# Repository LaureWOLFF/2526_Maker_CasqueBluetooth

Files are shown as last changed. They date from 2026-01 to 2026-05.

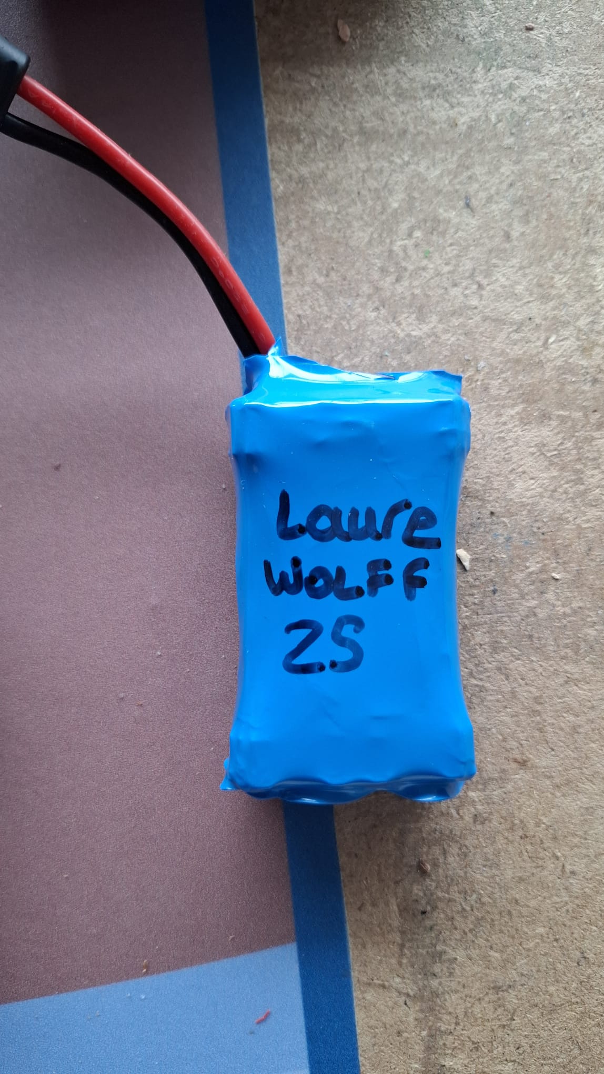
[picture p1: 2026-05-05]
TDs/Batterie/WhatsApp Image 2026-05-05 at 19.35.17.jpeg

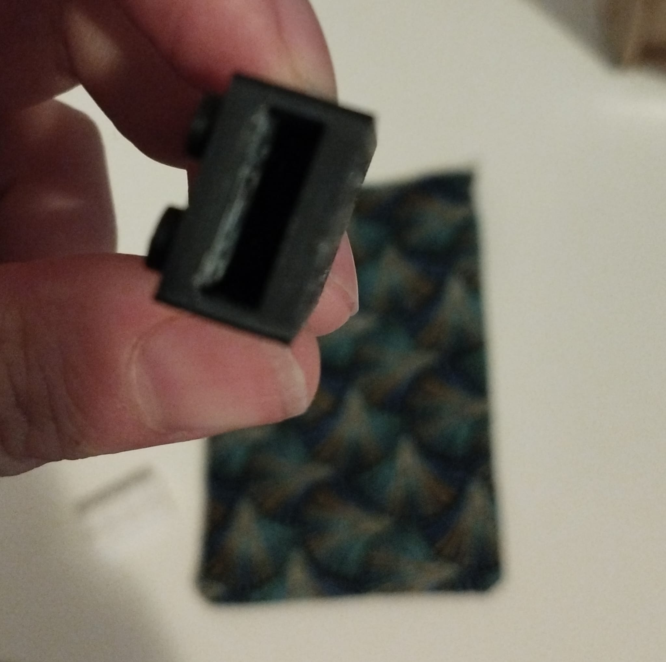
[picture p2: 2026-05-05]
TDs/impressions 3D et couture/WhatsApp Image 2026-05-05 at 10.13.26.jpeg

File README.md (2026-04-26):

# 🎧 2526_Maker_CasqueBluetooth: Création d'un casque bluetooth DIY

## 📌 Présentation du Projet

Le but de ce projet est de créer un casque bluetooth en mobilisant les compétences apprises lors de l'option **Maker** de deuxième année de l'**ENSEA**. Pour réaliser ce casque, le choix du microcontroleur c'est porté sur l'utilisation d'un **ESP32-S3-MINI-1-N8**. La structure mécanique a été entièrement modélisée sur **Onshape** avec une attention particulière portée à l'intégration électronique et à la durabilité tandis que la conception électronique a été réalisée sur Kicad.

### Caractéristiques Principales
* **Micronctroleur :** ESP32-S3-MINI-N8.
* **Diamètre des oreillettes :** 82 mm.
* **Interface :** Contrôle du volume et lecture via 3 boutons physiques (GPIO 0, 1, 2).
* **Connectivité :** USB-C 16 pins.
* **Architecture Audio :** Flux numérique I2S (Pins 6, 7, 8) vers DAC/Ampli.

---

## 🛠 Technologies & Outils
* **Mécanique :** Onshape (Modélisation 3D).
* **Électronique :** KiCad (Conception du PCB).
* **Développement :** Arduino IDE 1.8.19.

## 📋 État du Prototype
* **Hardware :** PCB soudé et fonctionnel (LED verte OK).
* **Mécanique :** Impression 3D terminée et finalisée.
* **Firmware :** En cours d'optimisation pour la reconnaissance USB Audio.

---

## ⚡L'impasse du Bluetooth classique sur l'ESP32-S3

Lors de la progammation du PCB, un problème est intervenu. Il est impossible de compiler le code car l'ESP32-S2-MINI-N8. En effet conttairement au téléphone qui a un protocole bluetooth pour l'audio de A2DP (Classic), l'ESP32 ne finctionne que en Bluetooth LE. Cette erreur dans le choix du composant a empecher de réliser  la finialisation de ce pojet. Car la bibliothèque de référence `ESP32-A2DP` est= incompatible avec cette puce. Le S3 est conçu pour le **Bluetooth LE (Low Energy)** et le futur standard **LE Audio**, qui nécessite un smartphone très récent.

    1. Modification du PCB
Pour palierà ce problème, une possibilité eest d'ajoutéé un module Bluetooth Audio dédié gérant le profil A2DP. Ainsi ainsi l'ESP32 serait utilisé pour traiter l'information (la munique) et le module pour la transmmetre. Cependant, le PCB devait être modifier et avec le délai serré, il était impossible de commander un nouveau PCB modifié.

    2. La solution Wi-Fi
Il existe une possibilitée d'utiliser le Wi-Fi pour le streaming (Spotify Connect). Cependant, le casque devenait dépendant d'un réseau Wi-Fi local, perdant son utilité en déplacement.

      3. La Solution USB DAC
Pour sauver le projet sans changer le PCB déjà soudé, une autre solution est envisageable vers un mode **USB DAC**. 
En utilisant les pins natives **D- (GPIO 19)** et **D+ (GPIO 20)** de l'ESP32-S3, le casque est reconnu comme une carte son externe par le téléphone. Ainsi, il y a la possibilité de transformer le prototype d'un casque bluetooth à un casque filiaire.

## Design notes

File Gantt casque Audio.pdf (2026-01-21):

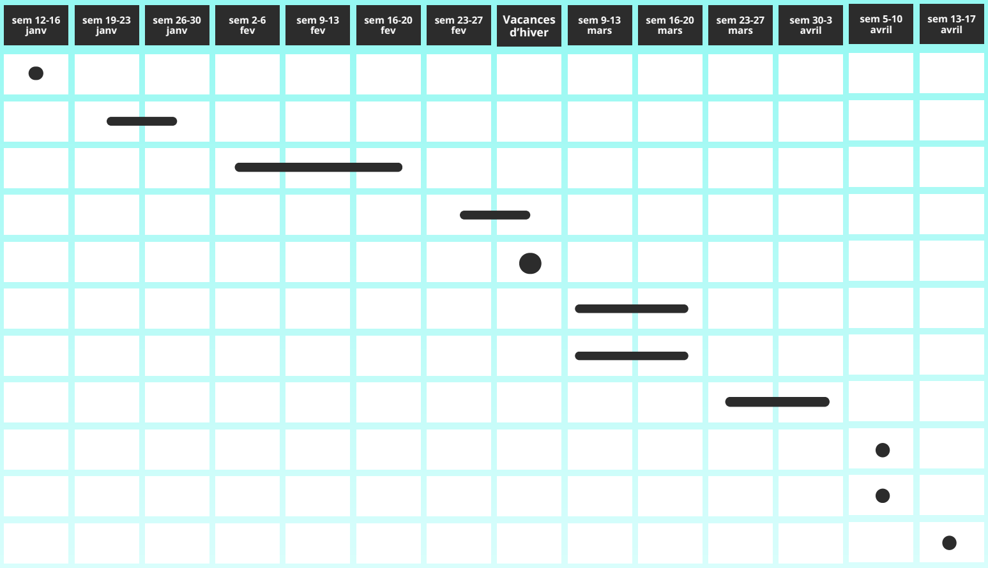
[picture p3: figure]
sem 12-16 janv; sem 19-23 janv; sem 26-30 janv; sem 2-6 fev; sem 9-13 fev; sem 16-20 fev; sem 23-27 fev; Vacances d’hiver; sem 9-13 mars; sem 16-20 mars; sem 23-27 mars; sem 30-3 avril; sem 5-10 avril; sem 13-17 avril

Recherche et commande
des composants

Définition du projet

Developpement du PCB

Commande et livraison du
PCB
Modélisation

Impression des éléments
mécanique

Soudure PCB

Programmation

Assemblage de l’ensemble

Test et validation

# Gantt diagram

Rendu / soutenance

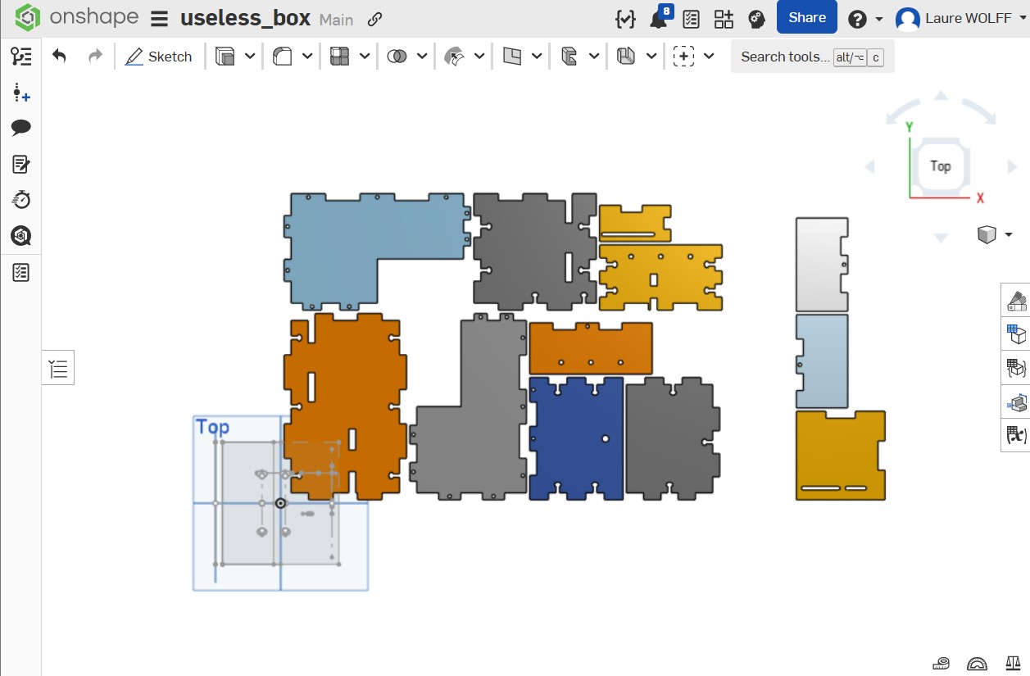
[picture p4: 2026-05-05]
TDs/découpeuse laser/CAO de la boite.jpg

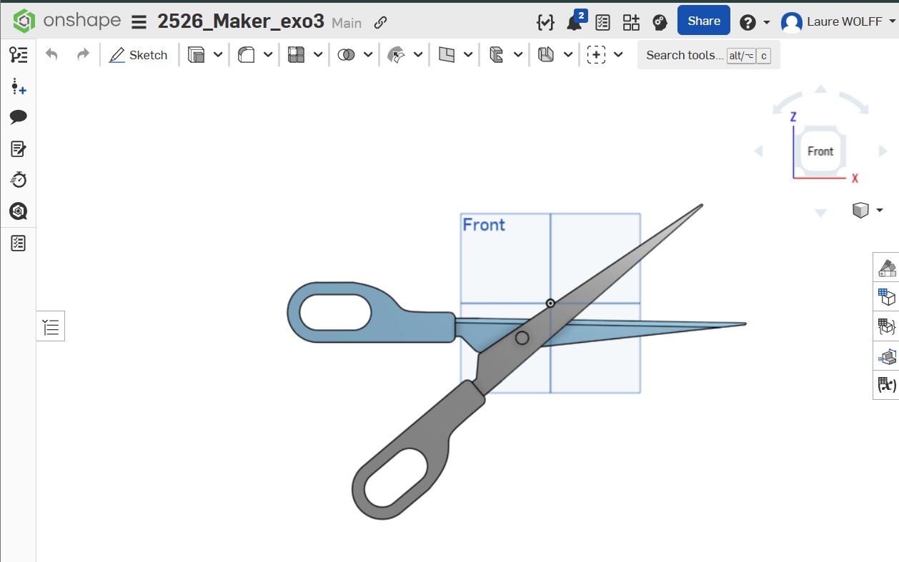
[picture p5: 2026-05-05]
TDs/CAO/CAO ciseaux.jpg

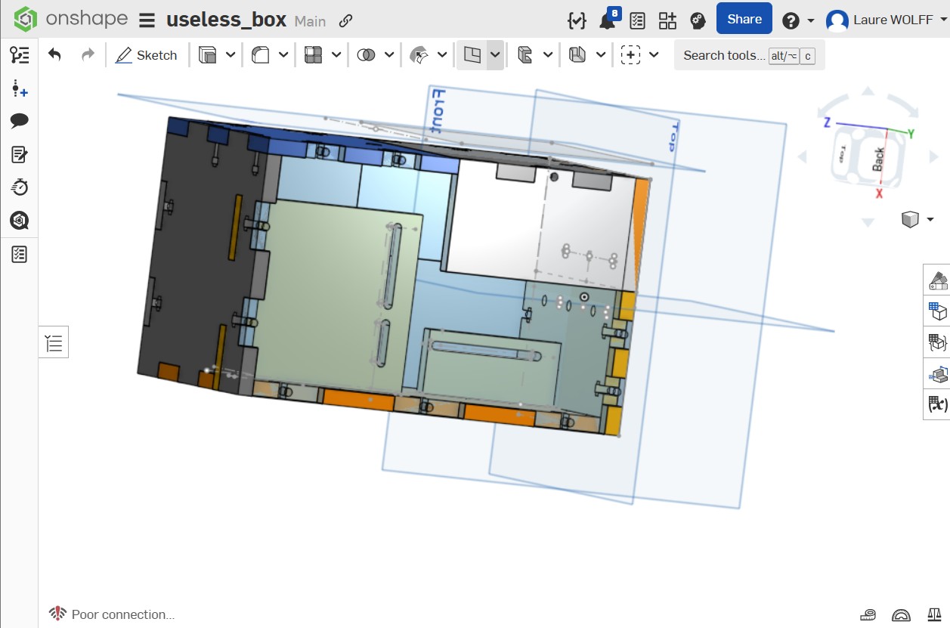
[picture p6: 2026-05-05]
TDs/découpeuse laser/visualisation 3D de la boite.jpg

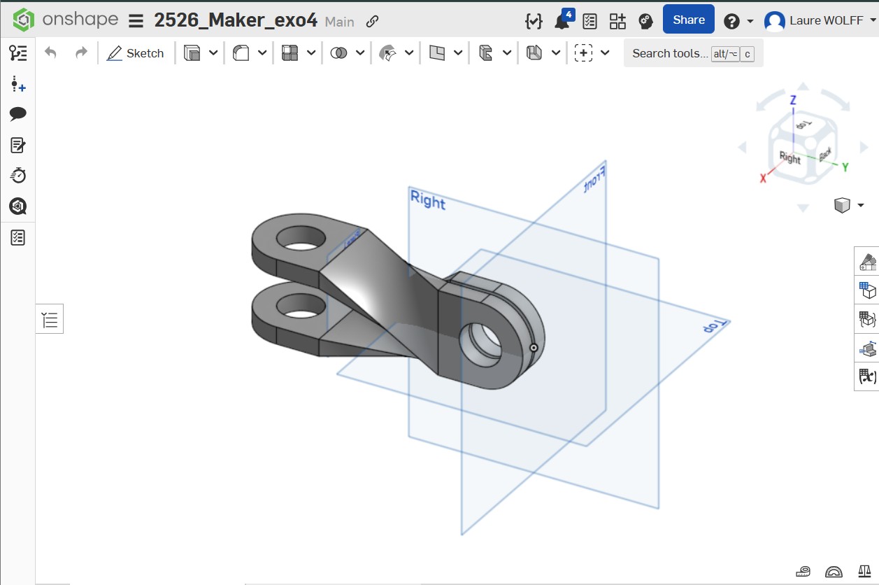
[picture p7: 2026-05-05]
TDs/CAO/CAO ecrou.jpg

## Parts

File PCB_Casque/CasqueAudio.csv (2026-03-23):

Reference | Value | Footprint | Datasheet | Qty | DNP | Exclude from BOM | Exclude from Board
C1,C2 | 1µ | Capacitor_SMD:C_0402_1005Metric_Pad0.74x0.62mm_HandSolder | ~ | 2
C3,C4 | 4.7µ | Capacitor_SMD:C_0402_1005Metric_Pad0.74x0.62mm_HandSolder | ~ | 2
C5 | 22µ | Capacitor_SMD:C_0603_1608Metric_Pad1.08x0.95mm_HandSolder | ~ | 1
C6,C9,C10 | 0.1µ | Capacitor_SMD:C_0402_1005Metric_Pad0.74x0.62mm_HandSolder | ~ | 3
C11,C12 | 10µ | Capacitor_SMD:C_0603_1608Metric_Pad1.08x0.95mm_HandSolder | ~ | 2
C14,C15,C16,C17 | 100n | Capacitor_SMD:C_0402_1005Metric_Pad0.74x0.62mm_HandSolder | ~ | 4
D1 | LED | LED_SMD:LED_0603_1608Metric_Pad1.05x0.95mm_HandSolder | ~ | 1
H1,H2,H3,H4 | MountingHole | MountingHole:MountingHole_2.7mm_M2.5 | ~ | 4 |  | Excluded from BOM
J1 | USB_C_Receptacle_USB2.0_16P | Connector_USB:USB_C_Receptacle_GCT_USB4105-xx-A_16P_TopMnt_Horizontal | https://www.usb.org/sites/default/files/documents/usb_type-c.zip | 1
J2 | Conn_01x02_Pin | Connector_JST:JST_PH_B2B-PH-K_1x02_P2.00mm_Vertical | ~ | 1
J3,J4,J5,J6 | Conn_01x01_Pin | TestPoint:TestPoint_Pad_D2.0mm | ~ | 4
R1,R2 | 5.1k | Resistor_SMD:R_0402_1005Metric_Pad0.72x0.64mm_HandSolder | ~ | 2
R3 | 470 | Resistor_SMD:R_0402_1005Metric_Pad0.72x0.64mm_HandSolder | ~ | 1
R4 | 4.7k | Resistor_SMD:R_0402_1005Metric_Pad0.72x0.64mm_HandSolder | ~ | 1
R5 | 200k | Resistor_SMD:R_0402_1005Metric_Pad0.72x0.64mm_HandSolder | ~ | 1
R7,R8,R9,R10,R11 | 10k | Resistor_SMD:R_0402_1005Metric_Pad0.72x0.64mm_HandSolder | ~ | 5
SW1,SW2,SW4 | SW_Push | Button_Switch_THT:SW_Tactile_SPST_Angled_PTS645Vx58-2LFS | ~ | 3
SW3,SW5 | SW_Push | 435171014816:435171014816 | ~ | 2
U1 | MCP73831-2-OT | Package_TO_SOT_SMD:SOT-23-5 | http://ww1.microchip.com/downloads/en/DeviceDoc/20001984g.pdf | 1
U2 | AP2112K-3.3 | Package_TO_SOT_SMD:SOT-23-5 | https://www.diodes.com/assets/Datasheets/AP2112.pdf | 1
U3 | ESP32-S3-MINI-1 | RF_Module:ESP32-S2-MINI-1 | https://www.espressif.com/sites/default/files/documentation/esp32-s3-mini-1_mini-1u_datasheet_en.pdf | 1
U4,U5 | MAX98357A | Package_DFN_QFN:TQFN-16-1EP_3x3mm_P0.5mm_EP1.23x1.23mm | https://www.analog.com/media/en/technical-documentation/data-sheets/MAX98357A-MAX98357B.pdf | 2

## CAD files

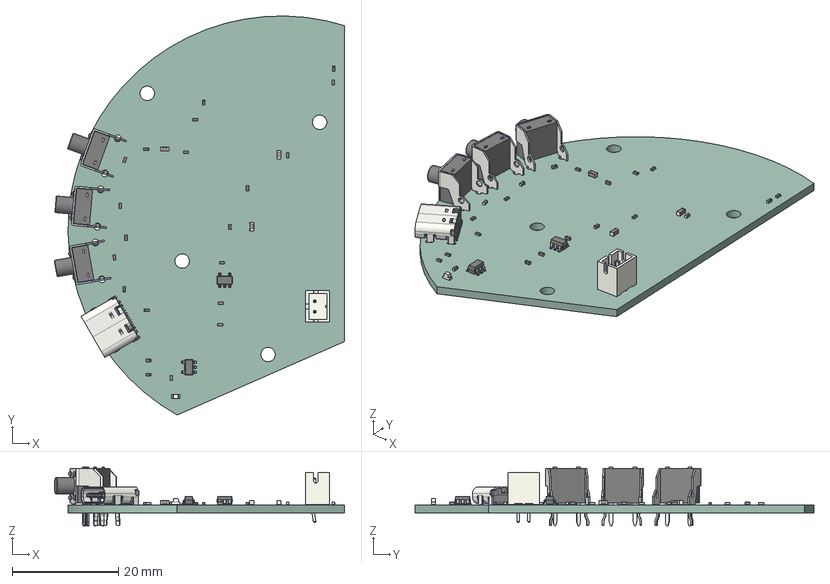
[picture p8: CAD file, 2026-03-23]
Design_PCB/PCB_Casque.step
54.5 x 75.0 x 11.0 mm
R_0402_1005Metric x 10
SW_Tactile_SPST_Angled_PTS645Vx58-2LFS x 3
C_0402_1005Metric x 11
SOT-23-5 x 2
LED_0603_1608Metric
C_0603_1608Metric x 3
USB_C_Receptacle_GCT_USB4105-xx-A_16P_TopMnt_Horizontal
JST_PH_B2B-PH-K_1x02_P2.00mm_Vertical
PCB_Casque_PCB

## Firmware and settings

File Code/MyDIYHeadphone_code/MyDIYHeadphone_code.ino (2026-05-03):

#ifndef CONFIG_BT_ENABLED
#define CONFIG_BT_ENABLED 1
#endif

#include "AudioTools.h"
#include "BluetoothA2DPSink.h"

// Définition des boutons
const int VOL_UP     = 0; 
const int VOL_DOWN   = 2; 
const int PAUSE_PLAY = 1;

BluetoothA2DPSink MyDIYHeadphone;

void setup() {
  Serial.begin(115200);
  
  pinMode(VOL_UP, INPUT_PULLUP);
  pinMode(VOL_DOWN, INPUT_PULLUP);
  pinMode(PAUSE_PLAY, INPUT_PULLUP);

  // Config I2S spécifique ESP32-S3
  i2s_pin_config_t my_pin_config = {
        .bck_io_num = 6,    
        .ws_io_num = 7,     
        .data_out_num = 8, 
        .data_in_num = I2S_PIN_NO_CHANGE
  };
  
  MyDIYHeadphone.set_pin_config(my_pin_config);
  MyDIYHeadphone.start("LW_Headphone");
}

void loop() {
  if (digitalRead(PAUSE_PLAY) == LOW) {

    if (MyDIYHeadphone.get_audio_state() == ESP_A2D_AUDIO_STATE_STARTED) {
      MyDIYHeadphone.pause();
    } else {
      MyDIYHeadphone.play();
    }
    delay(1000); 
    }

    

  if (digitalRead(VOL_UP) == LOW) {
        MyDIYHeadphone.set_volume(MyDIYHeadphone.get_volume() + 5);
        delay(200); 
    }

  if (digitalRead(VOL_DOWN) == LOW) {
        MyDIYHeadphone.set_volume(MyDIYHeadphone.get_volume() - 5);
        delay(200); 
  }
}

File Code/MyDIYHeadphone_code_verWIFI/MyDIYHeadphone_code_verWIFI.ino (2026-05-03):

#include "Arduino.h"
#include "WiFi.h"
#include "Audio.h" // Bibliothèque de Schreibfaul1

// --- CONFIGURATION PINS ESP32-S3 ---
// Vérifie bien tes branchements physiques !
#define I2S_BCLK      6
#define I2S_LRCK      7
#define I2S_DOUT      8

// --- TES ACCÈS WI-FI ---
const char* ssid =     "Mon-casque";
const char* password = "mdp";

Audio audio;

void setup() {
    Serial.begin(115200);
    
    // 1. Connexion au réseau
    WiFi.begin(ssid, password);
    Serial.print("Connexion au Wi-Fi");
    while (WiFi.status() != WL_CONNECTED) {
        delay(500);
        Serial.print(".");
    }
    Serial.println("\nConnecté !");

    // 2. Configuration du DAC (I2S)
    // C'est ici qu'on définit les pins 6, 7 et 8
    audio.setPinout(I2S_BCLK, I2S_LRCK, I2S_DOUT);
    
    // 3. Réglage du volume (Echelle de 0 à 21)
    // Attention, commence doucement pour tes oreilles !
    audio.setVolume(12); 

    // 4. Flux de test : Radio FIP (MP3 128kbps)
    // Si ce flux démarre, tes haut-parleurs vont chanter.
    audio.connecttohost("http://direct.fipradio.fr/live/fip-midfi.mp3");
}

void loop() {
    // Crucial : La bibliothèque a besoin de cette fonction pour décoder le son
    audio.loop(); 
}

// --- OPTIONS DE DEBUG (Affichent les infos dans le moniteur série) ---
void audio_info(const char *info){
    Serial.print("Audio Info: "); Serial.println(info);
}

void audio_bitrate(const char *info){
    Serial.print("Qualité : "); Serial.print(info); Serial.println(" bits/s");
}

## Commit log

2026-01-21 Ajout des pièces CAO 21/01
    [Piece_1.step, ciseau.step, joints.step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]
2026-01-26 sans le CAD hors projet
    [Piece_1.step, ciseau.step, joints.step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]
2026-03-19 Prototypage du PCB
    [DacAmpli.kicad_sch, DacAmpli1.kicad_sch, ESP23_s3_mini_1_N8.kicad_sch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]
2026-03-23 ajout du PCB version final + elt du design
    [CasqueAudio.csv, ESP23_s3_mini_1_N8.kicad_sch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]
2026-05-03 Video de 1min20
2026-05-05 Ajout des TDs
2026-05-05 Ajout de la batterie
